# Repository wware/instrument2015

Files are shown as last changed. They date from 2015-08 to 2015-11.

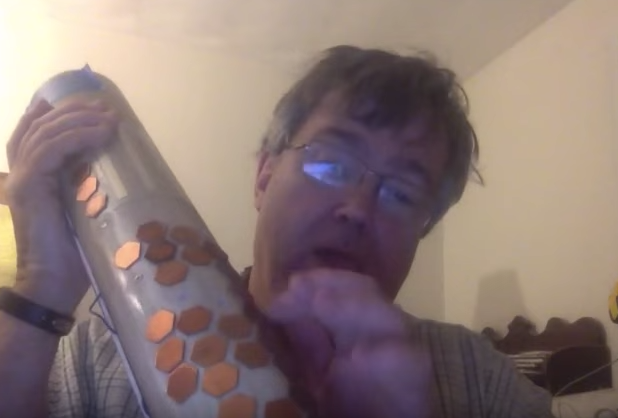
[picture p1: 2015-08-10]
ToobaStill.png

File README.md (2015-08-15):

<!--
pip install markdown
python -m markdown README.md > README.html
-->

The Tooba is an electronic musical instrument built into a piece of PVC tubing (hence the name). It borrows principles from the Moog-style analog music synthesizers of past decades.

Video demo of the instrument (https://www.youtube.com/watch?v=QGhZ0tecp60)

Way back when, one of my friends in high school was a guy named [Dave Wilson](http://www.matrixsynth.com/2010/08/rip-david-hillel-wilson-curator-of-new.html) whose father got him into 1970s-era Moog-style analog electronic music synthesizers. Dave created a museum of historical synthesizers in his home in Nashua, New Hampshire. Throughout our high school and college years, we exchanged ideas and circuits and bits of lore for various synthesizer hacks.

Music synthesizers of that era were actually special-purpose [analog computers](https://en.wikipedia.org/wiki/Analog_computer), performing arithmetic operations with [integrators, summers, and other such circuits](https://courses.engr.illinois.edu/ece486/labs/lab1/analog_computer_manual.pdf). These computations can be performed digitally by a microprocessor or special-purpose digital circuit (e.g. FPGA). So Dave and I both at various points and in various contexts wrote code to do that.

Sound generation in the Tooba (and keyboard scanning and voice assignment) is done in [C++](https://github.com/wware/instrument2015/blob/master/nextstage/teensy/teensy.ino) running on a 32-bit ARM microcontroller.

Status, plans, etc
----

The first PVC prototype, the one shown at Providence on Aug 8th 2015, did all sound generation in the interrupt handler. More recently, the interrupt handler only transfers audio samples from a queue to the microcontroller's on-chip 12-bit DAC, and sound generation occurs in the loop() function.

* Doxygen stuff is now [online](http://wware.github.io/instrument2015/).
* Removing sound generation from the interrupt handler and moving it into the main loop solved a LOT of problems, and now I can run the interrupt at 40 kHz. But I am still hearing some aliasing, so I'll need a lowpass filter after the DAC. Use this [rail-to-rail op amp](http://www.digikey.com/product-detail/en/LT1677CN8%23PBF/LT1677CN8%23PBF-ND/962980).
* ADSR and other slow-moving things should perform real calculations at only around 50 Hz, not 40 or 50 kHz. In between calculations they should use linear interpolation. Four billion divided by 50K is 80K, so it’s fine to use 16 fraction bits to interpolate. This will significantly speed things up.
* Never copy or move blocks of data. Move pointers instead. The persistence data for a voice should live in one place and never move.
* The next step right now is to take the code in the Voice class and split it into VCO, VCA and ADSR classes. Then add a Noise class, a Scaler class, a Summer class, and a VCF class. The audio outputs of all these should be 24-bit signed integers in the range from -0x80_0000 to 0x7F_FFFF. Use asserts to make sure they never go outside that range.
* Set up a [monkey test framework](https://en.wikipedia.org/wiki/Monkey_test) that virtually pounds on the keyboard, and detects overflows, underruns, etc.
  * A [SWIG wrapper](http://swig.org/) will be very helpful with this.

Teensy 3.1 info
----

* [The Freescale Semiconductor web page](http://www.freescale.com/webapp/sps/site/prod_summary.jsp?code=K20_50) for the MK20DX256VLH7 processor used in the Teensy 3.1.
* [The datasheet](https://www.pjrc.com/teensy/K20P64M72SF1RM.pdf) that talks about GPIO programming starting on page 1331.
* [The Teensy 3.1 schematic](https://www.pjrc.com/teensy/schematic.html). PTB17 is the GPIO that I want to read. The Port B input register is at 0x400FF050. There is no MMU so no need for any mmap craziness.
* [Here](https://forum.pjrc.com/threads/25317-Assembly-coding-for-Teensy3-1) is a great discussion of embedding assembly in C code. Also see http://www.ethernut.de/en/documents/arm-inline-asm.html.
* [A C header file](http://www.keil.com/dd/docs/arm/freescale/kinetis/mk20d7.h) for registers in the MK20DX.
* [Some nice info](http://www.peter-cockerell.net/aalp/html/frames.html) on ARM assembly language.

Earlier prototype
----

I want to read the GPIO in assembly to accurately measure the period of the oscillator. This code ran on the June prototype and measured the capacitance of the touch sensitive keyboard. The capacitance was used in the RC time constant of a free-running oscillator and the idea here is to get a measurement roughly proportional to the period.

1. Set counter to zero.
2. If input is LOW, go to step 7.
3. Wait for a falling edge. Proceed when input is LOW.
4. Increment counter while waiting for rising edge. Proceed when input is HIGH.
5. Increment counter while waiting for falling edge. Proceed when input is LOW.
6. Go to step 10.
7. Wait for a rising edge. Proceed when input is HIGH.
8. Increment counter while waiting for falling edge. Proceed when input is LOW.
9. Increment counter while waiting for rising edge. Proceed when input is HIGH.
10. Return counter.

So that piece is assembly, and then in C you choose a touch contact and call that function. That should ensure that you read the keyboard about as fast as it can be read. The code for this is buried in [the sandbox directory](https://github.com/wware/instrument2015/blob/master/sandbox/prototype1/prototype1.ino#L7).

~~~
static int measurePeriod(void)
{
    // Step 1, set up registers
    int count = 0, x = 0, mask = 1 << 17, addr = 0x400ff050;
#   define READ_INPUT  "ldr %1, [%3]\n"     "ands %1, %1, %2\n"
#   define INC_COUNT   "add %0, %0, #1\n"
    asm volatile(
        // Step 2, if input is low go to step 7
        READ_INPUT
        "beq step7"                             "\n"
        // Step 3, wait for falling edge
        "step3:"                                "\n"

        ... lots more code ...

        "step10:"                               "\n"
        : "+r" (count), "+r" (x), "+r" (mask), "+r" (addr)
    );
    return count;
}
~~~

This works well in both the [Arduino/Teensy IDE](https://www.pjrc.com/teensy/teensyduino.html) and in the [online ARM C++ compiler](http://assembly.ynh.io/).

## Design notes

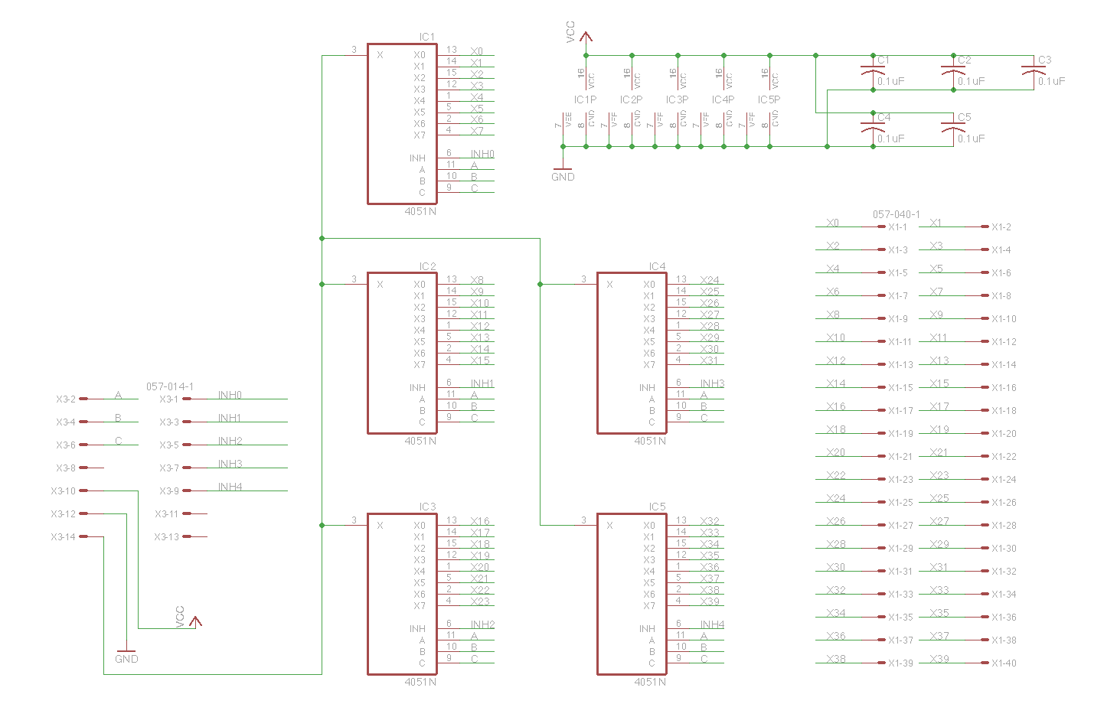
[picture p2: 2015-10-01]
boards/KeyMux40.png

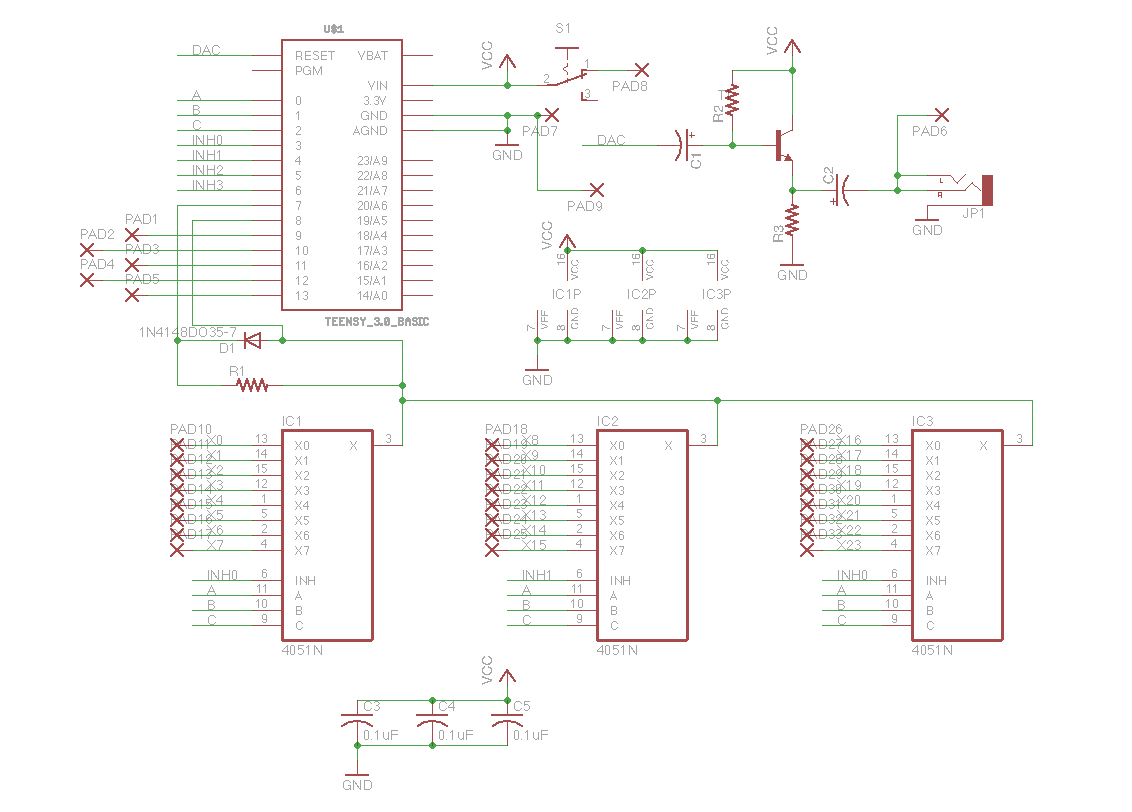
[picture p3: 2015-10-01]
boards/Trivisynth.png

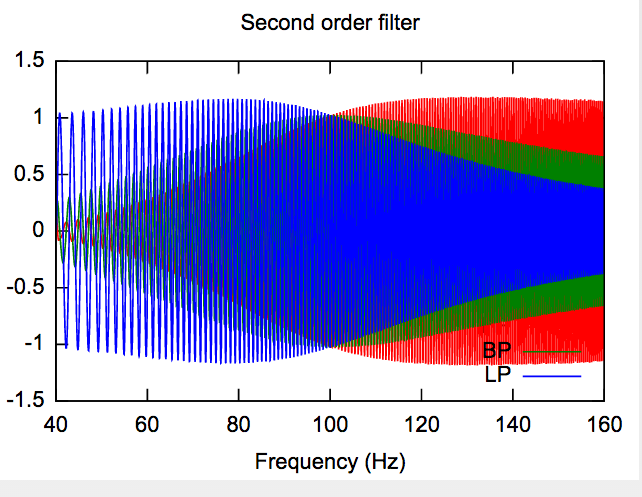
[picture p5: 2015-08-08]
sandbox/filter/gnuplot.png

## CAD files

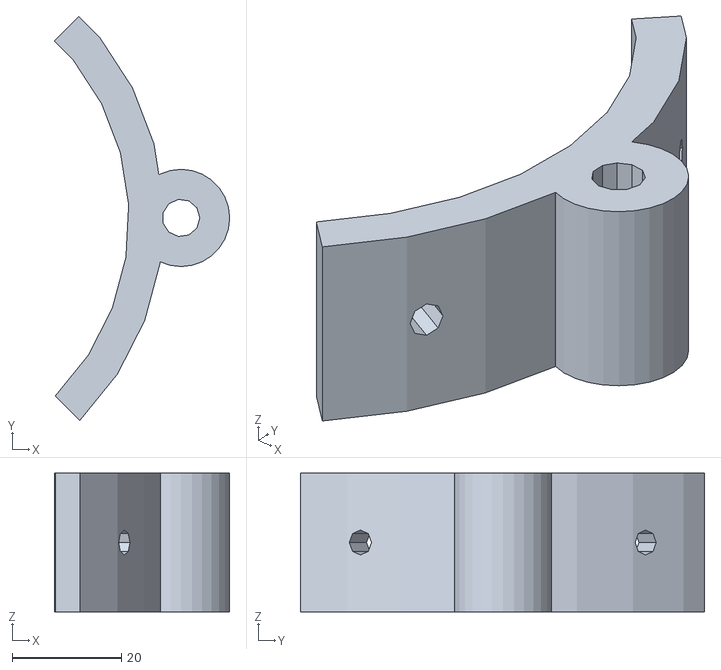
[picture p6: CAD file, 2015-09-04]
throd.stl
32.1 x 73.9 x 25.4

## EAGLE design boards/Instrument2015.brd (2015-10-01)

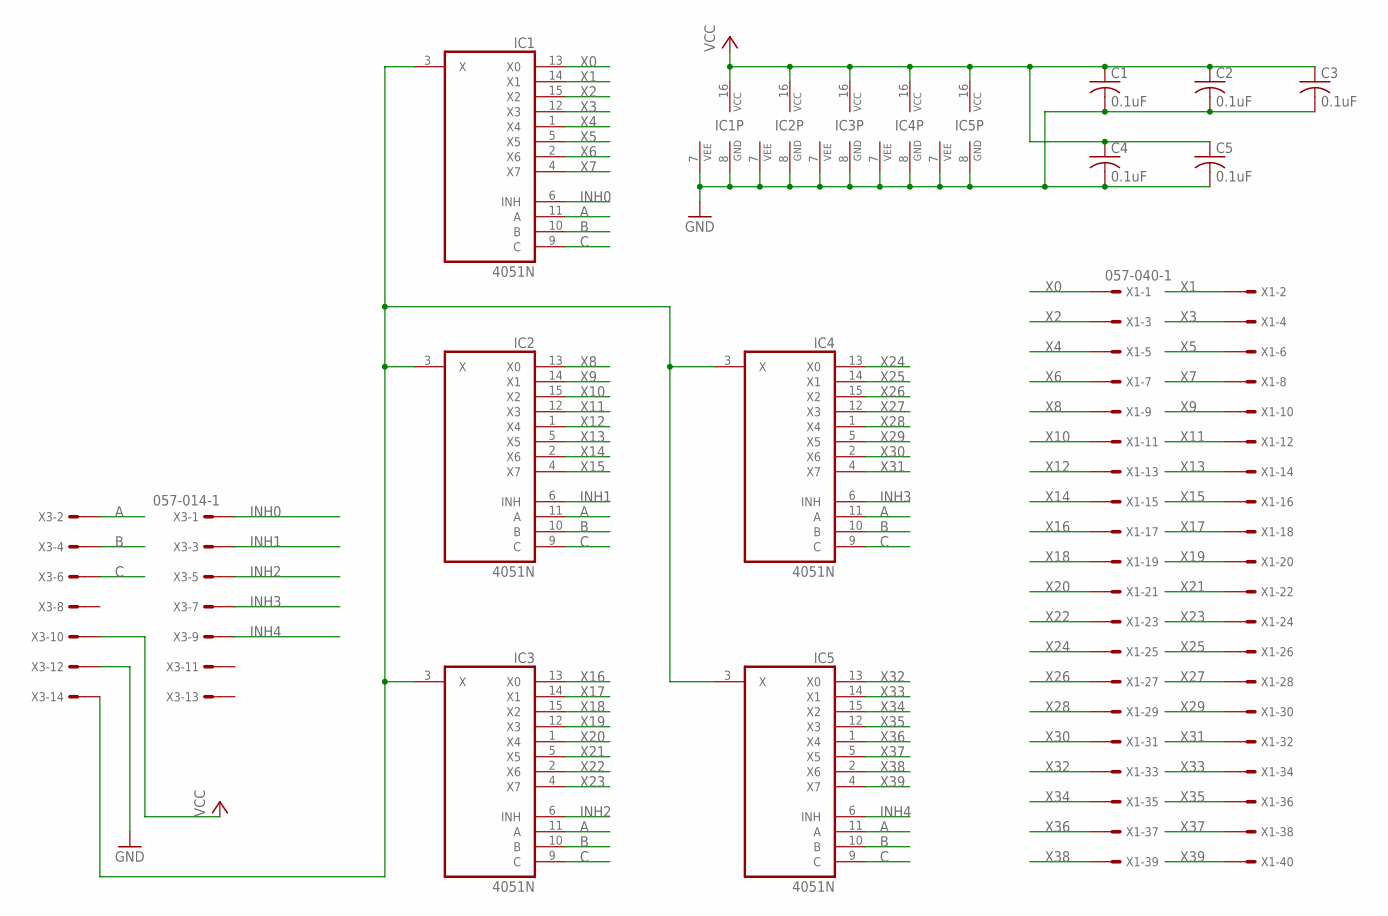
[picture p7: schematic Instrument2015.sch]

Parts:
C1, C2, C3, C4, C5: 0.1uF; C025-025X050
IC1, IC2, IC3, IC4, IC5: 4051N; DIL16
X1: 057-040-1
X3: 057-014-1

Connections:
A: IC1.11 (A), IC2.11 (A), IC3.11 (A), IC4.11 (A), IC5.11 (A), X3.2
B: IC1.10 (B), IC2.10 (B), IC3.10 (B), IC4.10 (B), IC5.10 (B), X3.4
C: IC1.9 (C), IC2.9 (C), IC3.9 (C), IC4.9 (C), IC5.9 (C), X3.6
GND: C1.2, C2.2, C3.2, C4.2, C5.2, IC1.7 (VEE), IC1.8 (GND), IC2.7 (VEE), IC2.8 (GND), IC3.7 (VEE), IC3.8 (GND), IC4.7 (VEE), IC4.8 (GND), IC5.7 (VEE), IC5.8 (GND), X3.12
INH0: IC1.6 (INH), X3.1
INH1: IC2.6 (INH), X3.3
INH2: IC3.6 (INH), X3.5
INH3: IC4.6 (INH), X3.7
INH4: IC5.6 (INH), X3.9
unnamed: IC1.3 (X), IC2.3 (X), IC3.3 (X), IC4.3 (X), IC5.3 (X), X3.14
VCC: C1.1, C2.1, C3.1, C4.1, C5.1, IC1.16 (VCC), IC2.16 (VCC), IC3.16 (VCC), IC4.16 (VCC), IC5.16 (VCC), X3.10
X0: IC1.13 (X0), X1.1
X1: IC1.14 (X1), X1.2
X2: IC1.15 (X2), X1.3
X3: IC1.12 (X3), X1.4
X4: IC1.1 (X4), X1.5
X5: IC1.5 (X5), X1.6
X6: IC1.2 (X6), X1.7
X7: IC1.4 (X7), X1.8
X8: IC2.13 (X0), X1.9
X9: IC2.14 (X1), X1.10
X10: IC2.15 (X2), X1.11
X11: IC2.12 (X3), X1.12
X12: IC2.1 (X4), X1.13
X13: IC2.5 (X5), X1.14
X14: IC2.2 (X6), X1.15
X15: IC2.4 (X7), X1.16
X16: IC3.13 (X0), X1.17
X17: IC3.14 (X1), X1.18
X18: IC3.15 (X2), X1.19
X19: IC3.12 (X3), X1.20
X20: IC3.1 (X4), X1.21
X21: IC3.5 (X5), X1.22
X22: IC3.2 (X6), X1.23
X23: IC3.4 (X7), X1.24
X24: IC4.13 (X0), X1.25
X25: IC4.14 (X1), X1.26
X26: IC4.15 (X2), X1.27
X27: IC4.12 (X3), X1.28
X28: IC4.1 (X4), X1.29
X29: IC4.5 (X5), X1.30
X30: IC4.2 (X6), X1.31
X31: IC4.4 (X7), X1.32
X32: IC5.13 (X0), X1.33
X33: IC5.14 (X1), X1.34
X34: IC5.15 (X2), X1.35
X35: IC5.12 (X3), X1.36
X36: IC5.1 (X4), X1.37
X37: IC5.5 (X5), X1.38
X38: IC5.2 (X6), X1.39
X39: IC5.4 (X7), X1.40

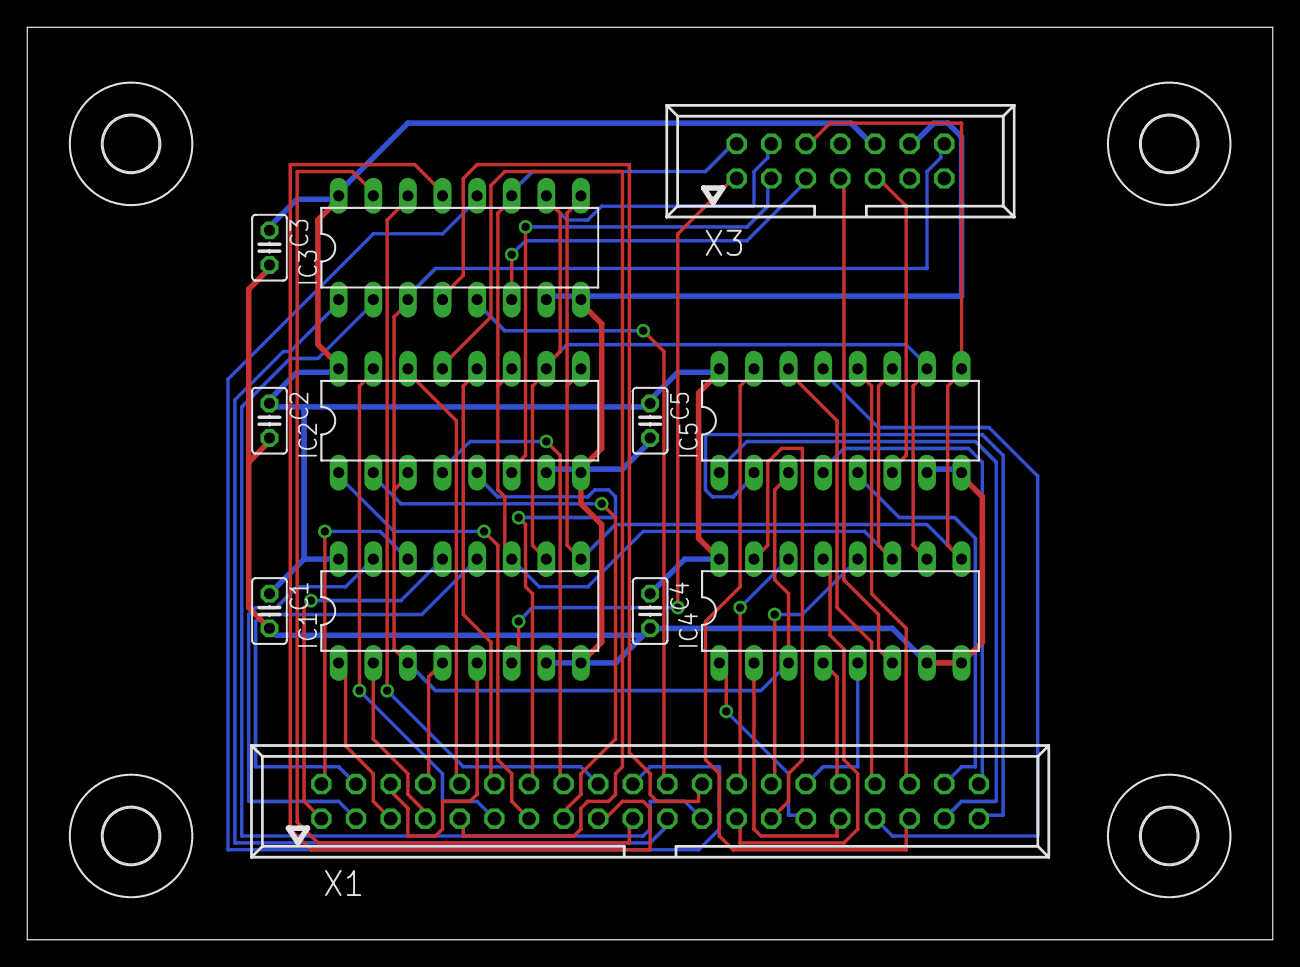
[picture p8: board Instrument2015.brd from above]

Board: 2 copper layers, 91.4 x 67.0 mm, 16 parts (0 on the bottom side), 51 nets.

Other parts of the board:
U$1, U$2, U$3, U$4: 4,1

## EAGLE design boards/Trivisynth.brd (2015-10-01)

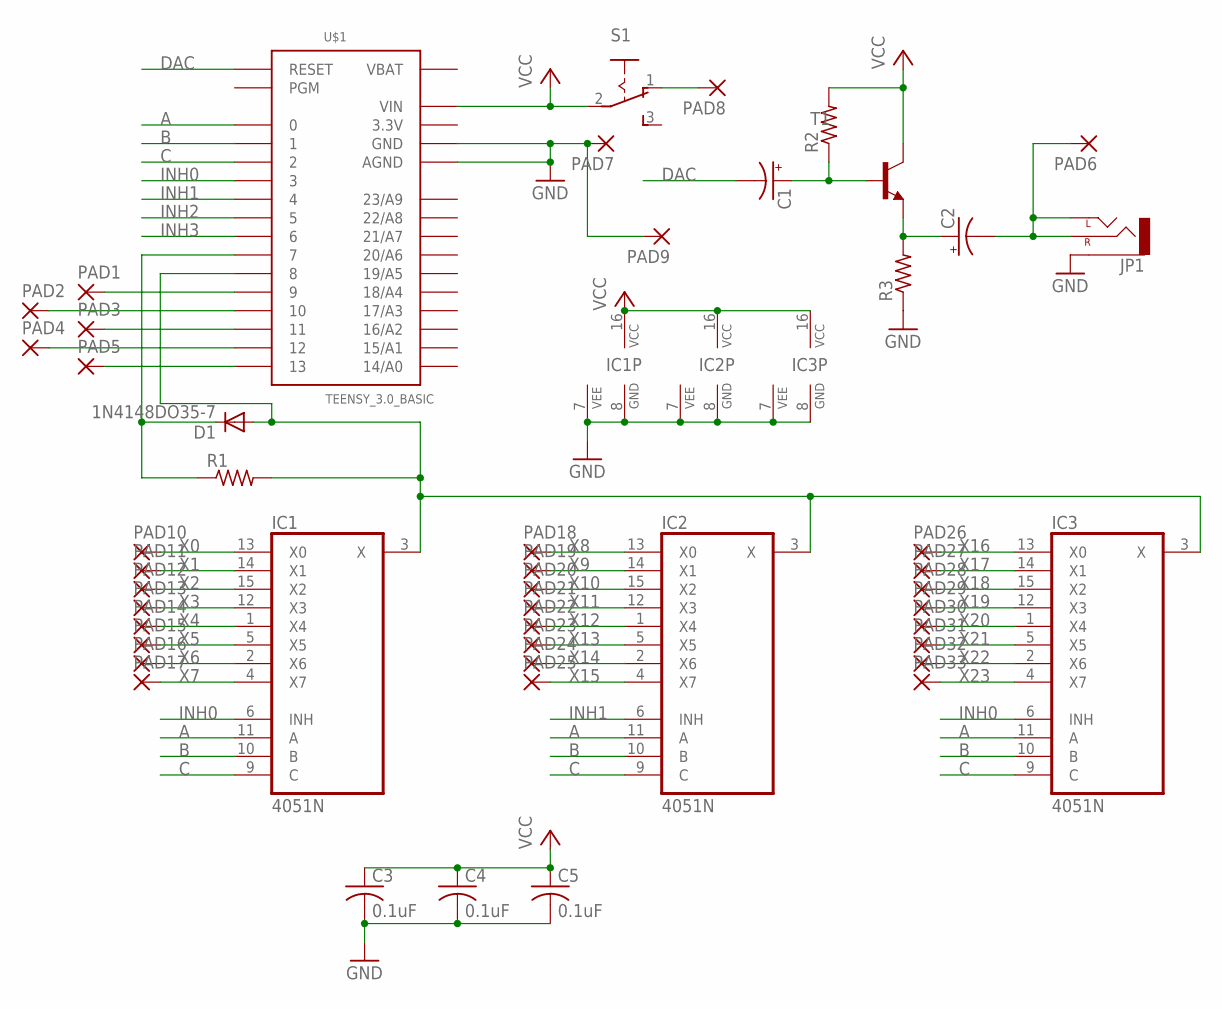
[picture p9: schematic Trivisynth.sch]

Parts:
C1, C2: CPOL-USE2-5; E2-5
C3, C4, C5: 0.1uF; C025-025X050
D1: 1N4148DO35-7; DO35-7
IC1, IC2, IC3: 4051N; DIL16
JP1: AUDIO-JACKPTH; AUDIO-JACK
PAD1, PAD2, PAD3, PAD4, PAD5, PAD6, PAD7, PAD8, PAD9, PAD10, PAD11, PAD12, PAD13, PAD14, PAD15, PAD16, PAD17, PAD18, PAD19, PAD20, PAD21, PAD22, PAD23, PAD24, PAD25, PAD26, PAD27, PAD28, PAD29, PAD30, PAD31, PAD32, PAD33: 2,15/1,0
R1, R2, R3: R-US_0207/10; 0207/10
S1: 255SB
T1: -NPN-TO92-EBC; TO92-EBC
U$1: TEENSY_3.0_BASIC

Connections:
3.3V: U$1.3.3V, U$1.3.3V1 (3.3V)
A: IC1.11 (A), IC2.11 (A), IC3.11 (A), U$1.0
B: IC1.10 (B), IC2.10 (B), IC3.10 (B), U$1.1
C: IC1.9 (C), IC2.9 (C), IC3.9 (C), U$1.2
DAC: C1.-, U$1.RESET
GND: C3.2, C4.2, C5.2, IC1.7 (VEE), IC1.8 (GND), IC2.7 (VEE), IC2.8 (GND), IC3.7 (VEE), IC3.8 (GND), JP1.SLEEVE, PAD7.1, PAD9.1, R3.1, U$1.AGND, U$1.GND, U$1.GND1 (GND)
INH0: IC1.6 (INH), IC3.6 (INH), U$1.3
INH1: IC2.6 (INH), U$1.4
INH2: U$1.5
INH3: U$1.6
unnamed: PAD8.1, S1.1 (O)
unnamed: D1.A, IC1.3 (X), IC2.3 (X), IC3.3 (X), R1.2, U$1.8
unnamed: C1.+, R2.1, T1.B
unnamed: C2.+, R3.2, T1.E
unnamed: D1.C, R1.1, U$1.7
unnamed: C2.-, JP1.RING (RIGHT), JP1.TIP (LEFT), PAD6.1
unnamed: PAD1.1, U$1.9
unnamed: PAD2.1, U$1.10
unnamed: PAD3.1, U$1.11
unnamed: PAD4.1, U$1.12
unnamed: PAD5.1, U$1.13
VBAT: U$1.VBAT
VCC: C3.1, C4.1, C5.1, IC1.16 (VCC), IC2.16 (VCC), IC3.16 (VCC), R2.2, S1.2, T1.C, U$1.VIN
X0: IC1.13 (X0), PAD10.1
X1: IC1.14 (X1), PAD11.1
X2: IC1.15 (X2), PAD12.1
X3: IC1.12 (X3), PAD13.1
X4: IC1.1 (X4), PAD14.1
X5: IC1.5 (X5), PAD15.1
X6: IC1.2 (X6), PAD16.1
X7: IC1.4 (X7), PAD17.1
X8: IC2.13 (X0), PAD18.1
X9: IC2.14 (X1), PAD19.1
X10: IC2.15 (X2), PAD20.1
X11: IC2.12 (X3), PAD21.1
X12: IC2.1 (X4), PAD22.1
X13: IC2.5 (X5), PAD23.1
X14: IC2.2 (X6), PAD24.1
X15: IC2.4 (X7), PAD25.1
X16: IC3.13 (X0), PAD26.1
X17: IC3.14 (X1), PAD27.1
X18: IC3.15 (X2), PAD28.1
X19: IC3.12 (X3), PAD29.1
X20: IC3.1 (X4), PAD30.1
X21: IC3.5 (X5), PAD31.1
X22: IC3.2 (X6), PAD32.1
X23: IC3.4 (X7), PAD33.1

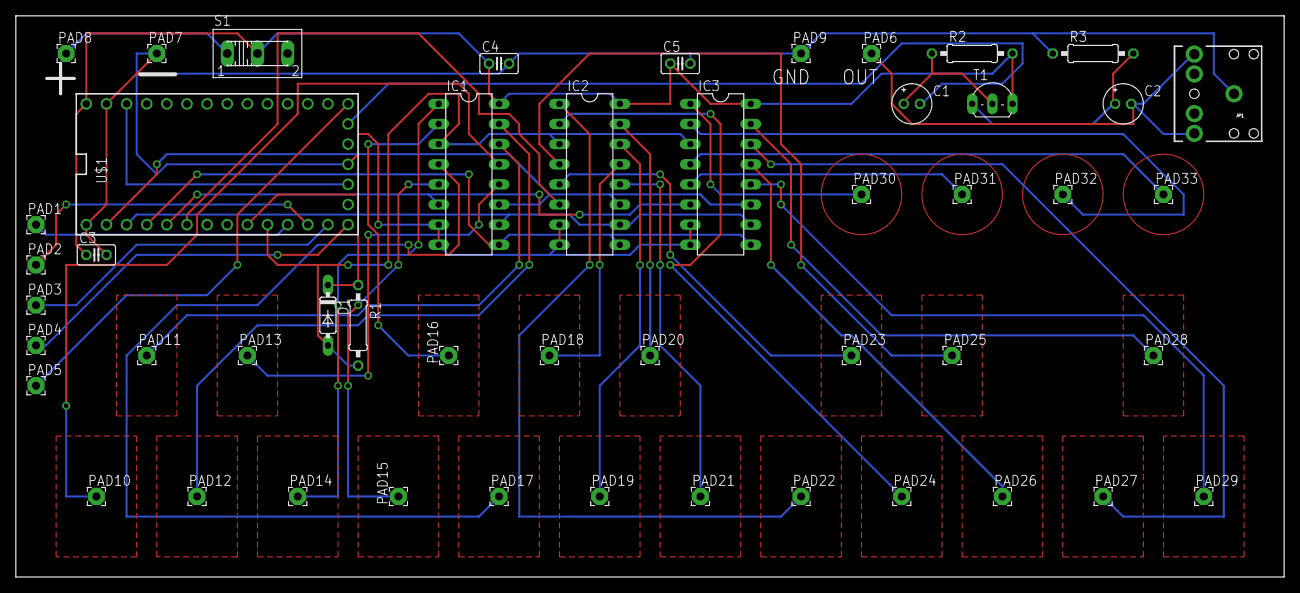
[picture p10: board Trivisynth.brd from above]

Board: 2 copper layers, 160.0 x 70.8 mm, 49 parts (0 on the bottom side), 44 nets.

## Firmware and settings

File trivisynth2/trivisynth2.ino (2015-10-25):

#include <TimerOne.h>

#include "synth.h"
#include "voice.h"
#include "tests.h"

#define DIAGNOSTICS 0
#define KEYBOARD 1
#define NUM_KEYS 24

/** @file */

class ThreadSafeSynth : public Synth
{
    void write_sample(void) {
        cli();
        Synth::write_sample();
        sei();
    }
};

// Port A, Port B, Port D
uint32_t port_settings[3 * NUM_KEYS];

#define PORT_A 0x400FF000
#define PORT_B 0x400FF040
#define PORT_C 0x400FF080
#define PORT_D 0x400FF0C0

static inline void set_port(uint32_t port, uint32_t mask, uint32_t value) {
    // offset 4 is set output
    // offset 8 is clear output
    asm volatile(
        "str %1, [%0, #8]"              "\n"
        "str %2, [%0, #4]"              "\n"
        : "+r" (port), "+r" (mask), "+r" (value)
    );
}

class NoteKey : public Key
{
private:
    uint32_t threshold;

    uint32_t successive_approximate(uint32_t lo, uint32_t hi) {
        if (hi < lo) return successive_approximate(hi, lo);
        if (hi - lo <= 1) return hi;
        uint32_t mid = (lo + hi) >> 1;
        if (!read_n(mid))
            return successive_approximate(lo, mid);
        else
            return successive_approximate(mid, hi);
    }

    bool read_n(uint32_t n) {
        volatile uint32_t X = 0, Y = n, portd = PORT_D;

        set_port(PORT_A, 0x03000, port_settings[3 * id]);
        set_port(PORT_B, 0x30000, port_settings[3 * id + 1]);
        set_port(PORT_D, 0x00085, port_settings[3 * id + 2]);

        // offset 4 is set output
        // offset 8 is clear output
        // offset 16 is read input
        asm volatile(
            // digitalWrite(7, LOW);
            "mov %0, #0x04"                 "\n"
            "str %0, [%2, #8]"              "\n"

            // X = 20;
            "mov %0, #20"                   "\n"

            // while (X > 0) X--;
            "step1:"                        "\n"
            "subs %0, %0, #1"               "\n"
            "bne step1"                     "\n"

            // digitalWrite(7, HIGH);
            "mov %0, #0x04"                 "\n"
            "str %0, [%2, #4]"              "\n"

            // while (Y > 0) Y--;
            "step2:"                        "\n"
            "subs %1, %1, #1"               "\n"
            "bne step2"                     "\n"

            // X = digitalReadFast(8);
            "ldr %0, [%2, #16]"             "\n"
            "ands %0, %0, #0x08"            "\n"

            // digitalWrite(7, LOW);
            "mov %1, #0x04"                 "\n"
            "str %1, [%2, #8]"              "\n"
            : "+r" (X), "+r" (Y), "+r" (portd)
        );
        return !X;
    }

public:
    int fresh_calibrate(void) {
        threshold = 0;
        return calibrate();
    }

    int calibrate(void) {
        const int _max = 250;
        int previous = 0, n;
        for (n = 1; n < _max; n <<=1) {
            if (!read_n(n)) {
                threshold =
                    max(threshold, successive_approximate(previous, n) + 1);
                return threshold;
            }
            previous = n;
        }
        threshold = max(threshold, _max);   // out of luck, probably
        return threshold;
    }

    bool read(void) {
        return read_n(threshold);
    }
};

NoteKey *keyboard[NUM_KEYS];
int which_synth = 0;
ThreadSafeSynth s, s2, s3;
ISynth *synth_ary[3];

class FunctionKey : public NoteKey
{
    void keyup(void) { /* nada */ }
    void keydown(void) {
        int i;
        switch (id) {
            case 20:
                which_synth = (which_synth + 1) % 3;
                synth_ary[which_synth]->quiet();
                cli();
                use_synth(which_synth);
                sei();
                break;
            case 21:
                which_synth = (which_synth + 2) % 3;
                synth_ary[which_synth]->quiet();
                cli();
                use_synth(which_synth);
                sei();
                break;
            case 22:
                synth_ary[which_synth]->quiet();
                if (keyboard[0]->pitch > -24) {
                    for (i = 0; i < NUM_KEYS - 4; i++) {
                        keyboard[i]->pitch -= 12;
                    }
                }
                break;
            case 23:
                synth_ary[which_synth]->quiet();
                if (keyboard[0]->pitch < 12) {
                    for (i = 0; i < NUM_KEYS - 4; i++) {
                        keyboard[i]->pitch += 12;
                    }
                }
                break;
            default:
                break;
        }
    }
};

extern uint32_t tune[];
uint32_t start_time;

/**
 * The timer interrupt takes audio samples from the queue and feeds
 * them to the 12-bit DAC. If there is a queue underrun, it turns on
 * the LED briefly but visibly.
 */
void timer_interrupt(void)
{
    static uint8_t led_time;
    uint32_t x;
    if (get_synth()->get_sample(&x) == 0) {
        analogWrite(A14, x);
    } else {
        led_time = 100;
    }
    if (led_time > 0) {
        led_time--;
        digitalWrite(LED_BUILTIN, HIGH);
    } else {
        digitalWrite(LED_BUILTIN, LOW);
    }
}

/**
 * Note that there are different numbers of voices assigned for the
 * different types of voice. The more complicated a voice is, the
 * less polyphony is possible. There are two ways to address this.
 *
 * * Lower the sampling rate, which adversely impacts sound quality.
 * * Speed up the code. That means doing a lot of profiling
 *   (best done with a GPIO pin and an oscilloscope in this situation)
 *   and then write tighter C++ code and possibly some assembly language.
 */
void setup() {
    uint8_t i, j;
#if DIAGNOSTICS
    Serial.begin(9600);
    while (!Serial) {
        ; // wait for serial port to connect. Needed for native USB port only
    }
#endif
    start_time = micros();
    /*
     * The more complicated a voice is, the less polyphony is possible.
     * There are two ways to address this. One is to lower the sampling
     * rate (which adversely impacts sound quality), and speeding up the
     * code. That means doing a lot of profiling (best done with a GPIO
     * pin and an oscilloscope in this situation) possibly followed by
     * tighter C++ code and possibly some assembly language.
     */
#define NUM_NOISY_VOICES  3
#define NUM_SIMPLE_VOICES  12
#define NUM_SQUARE_VOICES  6
    synth_ary[0] = &s;
    synth_ary[1] = &s2;
    synth_ary[2] = &s3;
    for (i = 0; i < NUM_SIMPLE_VOICES; i++)
        s.add(new SimpleVoice());
    for (i = 0; i < NUM_SQUARE_VOICES; i++)
        s2.add(new TwoSquaresVoice());
    for (i = 0; i < NUM_NOISY_VOICES; i++)
        s3.add(new NoisyVoice());
    s.quiet();
    use_synth_array(synth_ary, 3);
    use_synth(0);
    analogWriteResolution(12);
    Timer1.initialize((int) (1000000 * DT));
    Timer1.attachInterrupt(timer_interrupt);
    pinMode(0, OUTPUT);  // B16  -- A
    pinMode(1, OUTPUT);  // B17  -- B
    pinMode(2, OUTPUT);  // D0   -- C
    pinMode(3, OUTPUT);  // A12  -- INH0
    pinMode(4, OUTPUT);  // A13  -- INH1
    pinMode(5, OUTPUT);  // D7   -- INH2
    pinMode(7, OUTPUT);  // D2   -- drive
    pinMode(8, INPUT_PULLUP);  // D3  -- sense
    pinMode(LED_BUILTIN, OUTPUT);

    for (i = 0; i < NUM_KEYS - 4; i++) {
        keyboard[i] = new NoteKey();
        keyboard[i]->id = i;
        keyboard[i]->pitch = i;
    }
    for ( ; i < NUM_KEYS; i++) {
        keyboard[i] = new FunctionKey();
        keyboard[i]->id = i;
        keyboard[i]->pitch = 0;
    }

    for (i = 0; i < NUM_KEYS; i++) {
        uint32_t chip = i >> 3;
        // Port A
        port_settings[3 * i] =
            ((chip != 0) ? 0x1000 : 0) +
            ((chip != 1) ? 0x2000 : 0);
        // Port B
        port_settings[3 * i + 1] = (i & 3) << 16;
        // Port D
        port_settings[3 * i + 2] = ((i & 4) >> 2) +
            ((chip != 2) ? 0x80 : 0);
    }

    for (i = 0; i < NUM_KEYS; i++) {
        keyboard[i]->fresh_calibrate();
    }
    for (j = 0; j < 3; j++) {
        for (i = 0; i < NUM_KEYS; i++) {
            keyboard[i]->calibrate();
        }
    }
}

/**
 * Arduino loop function
 */
void loop(void) {
    int i;

#if DIAGNOSTICS
    int j;
    i = keyboard[1]->fresh_calibrate();
    for (j = 0; j < i; j++) Serial.print("*");
    Serial.println();
    delay(20);
#else
#if KEYBOARD
    for (i = 0; i < NUM_KEYS; i++)
        keyboard[i]->check();
#else
    uint32_t msecs = (micros() - start_time) / 1000;
    if (play_tune(tune, msecs)) {
        start_time = micros();
    }
#endif
    for (i = 0; i < 32; i++) {
        get_synth()->compute_sample();
    }
#endif
}

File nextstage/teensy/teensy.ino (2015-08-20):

/*
We have a 40 kHz or 50 kHz timer interrupt that handles sound
samples. First it writes the previously computed sample to the serial DAC.
Then it computes the sample for the next time.
*/

#if ! defined(__ARDUINO)
#define __ARDUINO 1
#include <TimerOne.h>
#endif

#include <stdlib.h>
#include <string.h>
#include <stdarg.h>
#include <math.h>

#include "common.h"
#include "voice.h"
#include "key.h"
#include "queue.h"

Voice v[NUM_VOICES];
Key *keyboard[NUM_KEYS];
Queue samples;

void timer_interrupt(void);

float small_random() {
    return -2.0 + 0.01 *
#if __ARDUINO
    random(400);
#else
    (rand() % 400);
#endif
}

void setup() {
    int i;
#if __ARDUINO
    analogWriteResolution(12);
    Timer1.initialize((int) (1000000 * DT));
    Timer1.attachInterrupt(timer_interrupt);
    pinMode(11, INPUT_PULLUP);
    pinMode(10, OUTPUT);
    digitalWrite(10, LOW);
    pinMode(2, OUTPUT);
    pinMode(3, OUTPUT);
    pinMode(4, OUTPUT);
    pinMode(5, OUTPUT);
    pinMode(6, OUTPUT);
    pinMode(7, OUTPUT);
    pinMode(8, OUTPUT);
    pinMode(9, OUTPUT);
    pinMode(LED_BUILTIN, OUTPUT);
#endif

    for (i = 0; i < NUM_KEYS; i++) {
        keyboard[i] = new Key();
        keyboard[i]->id = i;
        keyboard[i]->pitch = 440.0 * pow(1.0594631, i - 9);
    }
}


uint32_t get_12_bit_value(void)
{
    int i;
    int64_t x = 0;
    for (i = 0; i < NUM_VOICES; i++)
        x += v[i].output();
    x /= NUM_VOICES;
    return ((x >> 20) + 0x800) & 0xFFF;
}

/**
 * The timer interrupt takes audio samples from the queue and feeds
 * them to the 12-bit DAC. If there is a queue underrun, it turns on
 * the LED briefly but visibly.
 */
void timer_interrupt(void)
{
    static uint8_t led_time;
    uint32_t x;
    if (samples.read(&x) == 0) {
#if __ARDUINO
        analogWrite(A14, x);
#endif
    } else {
        led_time = 100;
    }
    if (led_time > 0) {
        led_time--;
#if __ARDUINO
        digitalWrite(LED_BUILTIN, HIGH);
#endif
    } else {
#if __ARDUINO
        digitalWrite(LED_BUILTIN, LOW);
#endif
    }
}

uint8_t read_key(uint32_t id)
{
    uint32_t Y = 0;
#if __ARDUINO
    uint32_t j = id, chip;
    digitalWrite(10, LOW);
    j = id;
    switch (id) {    // OOPS WIRING ERRORS
        case 0:
            j = 1;
            break;
        case 1:
            j = 0;
            break;
    }
    chip = j >> 3;
    digitalWrite(4, (j >> 2) & 1);
    digitalWrite(3, (j >> 1) & 1);
    digitalWrite(2, (j >> 0) & 1);
    digitalWrite(5, chip == 1);   // OOPS WIRING ERROR
    digitalWrite(6, chip == 0);
    digitalWrite(7, chip == 2);
    digitalWrite(8, chip == 3);
    digitalWrite(9, chip == 4);
    Y = 0;
    digitalWrite(10, HIGH);
    while (!digitalReadFast(11)) Y++;
    digitalWrite(10, LOW);
#endif
    return Y;
}

/**
 * Run the step function on each of the voices. Sum their outputs to
 * get a 12-bit sample, and put the sample in the queue. If the queue
 * is full, then hang onto the sample to try to enqueue it again next
 * time.
 */
void compute_sample(void) {
    int i;
    static uint32_t x, again = 0;

    if (!again) {
        for (i = 0; i < NUM_VOICES; i++)
            v[i].step();
        x = get_12_bit_value();
    }
#if __ARDUINO
    cli();
#endif
    again = samples.write(x);
#if __ARDUINO
    sei();
#endif
}

/**
 * Arduino loop function
 * @todo Read soft pots
 * @todo Read the left-hand keyboard
 * @todo Create Pitch class
 * @todo Map keys to reachable pitches
 */
void loop(void) {
    int i;

    for (i = 0; i < NUM_KEYS; i++)
        keyboard[i]->check();
    for (i = 0; i < 64; i++)
        compute_sample();
}

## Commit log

2015-07-26 Initial prototype, RPi as sound generator
2015-07-27 Scrap the RPi, run everything on the Teensy
2015-07-27 Set up sandbox, hack interrupt handlers, ARM assembly
2015-07-30 Arduino compiler warning nitpick
2015-08-08 Use correct constant for attack exponential
    [teensy.ino]
2015-08-08 Discrete time 2nd order filter without z transforms
2015-08-08 Hardware debug, assembly language, GPIOs, etc
2015-08-13 Gnuplot, OSX adaptations, bug fixes
    [teensy.ino]
2015-08-13 wire up the queue
2015-08-14 Bug fixes and improvements.
    [teensy.ino]
2015-08-17 more filter analysis in python
2015-08-17 filter with integer arithmetic, kinda rough
2015-08-18 tinker with filter datapaths, fix a small bug
2015-08-20 correct my WORST IDEA EVER
    [teensy.ino]
2015-08-20 filter is REALLY int math now
2015-08-20 use new filter
2015-08-20 bump up hysteresis, fix filter damping issue
2015-08-28 fixed some wiring errors
    [teensy.ino]
2015-09-04 threaded rod holder
    [throd.stl]
2015-10-01 PCB stuff
    [KeyMux40.brd, KeyMux40.sch, Trivisynth.brd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]
2015-10-02 fix an autocalibration bug
    [teensy.ino]
2015-10-25 Measurements, and bug fixes
    [teensy.ino]
2015-10-25 Start work on board for second instrument.
    [FullInstr.sch]
2015-10-25 Control 4051s with assembly language.
2015-11-27 Rename schematic, add an image and a BRD file.
    [FullInstr.sch, FullInstrument.brd, FullInstrument.sch]
2021-03-06 Cadsoft Eagle files for 4051 board
    [Instrument2015.brd, Instrument2015.sch]

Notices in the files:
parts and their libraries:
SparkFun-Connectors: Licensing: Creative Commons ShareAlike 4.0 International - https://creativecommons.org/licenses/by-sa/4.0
